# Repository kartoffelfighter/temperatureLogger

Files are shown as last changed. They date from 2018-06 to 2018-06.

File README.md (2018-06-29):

temperatureLogger Firmware alphaV2
-

**Table of contents**

 - Firmware description
 - Function description
 - New Functions
 - Comparison
 - Possibility for new milestone

**Firmware description**

temperatureLogger alphaV2 ist planned to be used for a temperature logging device based on esp8266.
The device sends its measured values using a json string to a php server api to be stored and viewed from users. temperatureLogger alphaV2 uses the new and changing pcb-layout, alphaV2 is work in progress and may be not stable to use.

alphaV2 will be recoded to a tick based firmware powered by interrupts by timer0. 
at this time alphaV2 runs millis() loop based, checking the lasted time running code, for the new sleep() function a tick based firmware is needed.

**Function description**

based on alphaV1 the firmware can already measure, sample and send values to the API (Server). 
In future, the functions should be better described here.

**New functions**
in alphaV2 especially the error handling an the improvin of new hardware-designed milestone should be implemented.

For future releases the should be a function to configure editable values from "settings.h" by API and interface.
A ping-pong communication should be implemented

**Comparison (to alphaV1)**

alphaV1 is made for the old pcb layout, some pins have changed.
alphaV2 has no more LCD support, also LCD support is not planned for the future.
alphaV2 implements new features, as a multiplexed ADC input for measuring multiple Analog Values with just one ADC.
*primary change* alphaV2 will be a tick (interrupt) based firmware for compatibility reasons to new boards in the future.

**next milestone for alphaV3**
the next milestone is planned for the first, etched pcb in january '18.

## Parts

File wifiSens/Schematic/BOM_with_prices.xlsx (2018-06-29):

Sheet: EK Übersicht
ID | Name | supplier | price per unit | link | Auf Lager | EK | Description | Datasheet
 | ESP8266 | diy_fans | 1.68 € | http://www.ebay.de/itm/ESP8266-ESP-12E-Serial-WIFI-Kabellos-Transceiver-Kabellos-Modul-LWIP-AP-STA/322715945383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 | 5 | 8.40 € | WiFi Module/µC | Link
 | MC34063 | bingogo | 0.05 € | http://www.ebay.de/itm/20Pcs-MC34063-SOP8-ON-REG-BUCK-BOOST-INV-8-DIP-NEW/232488914511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 | 20 | 1.00 € | BuckBoost stepup | Link | Projekt gesamt: | 72.22 €
 | AMS1117-3,3 | bingogo | 0.02 € | http://www.ebay.de/itm/50Stks-AMS1117-3-3-LM1117-3-3V-1A-SOT-223-Voltage-Regulator-top/232480428556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 | 50 | 1.00 € | LDO 3.3V | Link | Platine aktuell: | 6.96 €
 | DHT22 | diy_fans | 2.30 € | http://www.ebay.de/itm/DHT22-AM2302-Digital-Temperatur-Humidity-Sensor-Replace-SHT11-Arduino-Tackle/322667376882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 | 10 | 23.00 € | Temp Humid sensor | Link
 | Solar Panel | x-web-top | 1.00 € | http://www.ebay.de/itm/6V-1W-Solar-Panel-Modul-DIY-f%C3%BCr-Licht-Batterie-Handy-Ladeger%C3%A4te-Spielzeug-Nue/152683963489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 | 2 | 2.00 € |  | Link
 | 74HC132 | kessler-eletronic | 0.53 € | http://www.ebay.de/itm/5x-74HC132-SMD-NAND-Schmitt-Trigger-4-fach-SO14/111876817725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 | 5 | 2.64 € | NAND Schmit Trigger | Link
 | BSS84 | elektronik-direkt | 0.04 € | http://www.ebay.de/itm/30-x-BSS84-Kleinsignal-MOSFET-P-Channel/262316733258?ssPageName=STRK%3AMEBIDX%3AIT | 30 | 1.30 € | P-Channel Mosfet | Link
 | BC817-40 | elektronik-direkt | 0.04 € | http://www.ebay.de/itm/30-x-BC817-40-NPN-Kleinsignaltransistor-45V-500mA-SOT23/262290383155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 | 30 | 1.10 € | NPN Transistor | Link
 | LP2985 | elektronik-direkt | 0.33 € | http://www.ebay.de/itm/3x-9x-Ultra-Low-Dropout-Spannungsregler-LP2985-3-3-V-Kondensatoren-Platine/253119635496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 | 9 | 2.95 € | uLDO 3.3V | Link
 | PL2303hx | iamsn2008 | 0.36 € | http://www.ebay.de/itm/10Pcs-Pl2303hx-2303-Produktes-Ssop-28-Neues-Ic-N/232312842167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 | 10 | 3.56 € | USB UART Converter | Link
 | micro usb buchse | nn_745 | 0.12 € | http://www.ebay.de/itm/20x-Female-5Pin-SMT-Micro-USB-Socket-Adaptor-Connector-weiblich-Buchse-Anschluss/152776161688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 | 20 | 2.50 € |  | Link
 | tact switch smd | sell4joy | 0.08 € | http://www.ebay.de/itm/50pcs-4mmx4mmx1-5mm-4Pins-SMD-PCB-Momentary-Tact-Push-Button-Switch/391876007978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 | 50 | 4.01 € |  | Link
 | RB551v-30 | iamsn2008 | 0.03 € | http://www.ebay.de/itm/100Pcs-Rb551v-30-Te17-Schottky-Sod-323-Rohm-0-5A-20V-Neu-Ic-V/332195522274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 | 100 | 3.28 € | Schottky Diode | Link
 | mmbt8050 | iamsn2008 | 0.04 € | http://www.ebay.de/itm/50Pcs-Transistor-Mmbt8050-Sot-23-Npn-J3y-S8050-Smd-Neue-Ic-V/332191461244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 | 50 | 2.00 € | NPN Transistor | Link
 | µSD Socket | sellerbible | 0.09 € | https://www.ebay.de/itm/121688713134 | 50 | 4.48 € |  | Link
 | tp4056 | iamsn2008 | 0.08 € | https://www.ebay.de/itm/332214138541 | 50 | 4.00 € | LiPo Loader | Link
 | 12MhZ Oscillator |  | 0.17 € | https://www.ebay.de/itm/112688636210 | 30 | 5.00 € | Quarz Oszillator

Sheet: Exportet_BOM
Reference | Value | Footprint | Datasheet | Comment
SW1 | SW_Push | Buttons_Switches_SMD:SW_MEC_5GSH9 |  |  | Widerstände | Cap
SW2 | SW_Push | Buttons_Switches_SMD:SW_MEC_5GSH9 |  |  | 1x12 | 0,01µF
C13 | 0,01ÂµF | Capacitors_SMD:C_0603_HandSoldering |  |  | 4x470 | 0,1µF
C2 | 0,1ÂµF | Capacitors_SMD:C_0603_HandSoldering |  |  | 12x 0R0 | 100µF
C11 | 100ÂµF | Capacitors_SMD:C_0603_HandSoldering |  |  | 2x 100k | 6x 100nF
C18 | 100nF | Capacitors_SMD:C_0603_HandSoldering |  |  | 3x10k | 6x 10µF | 1x 10µ 1206 tantal
C19 | 100nF | Capacitors_SMD:C_0603_HandSoldering |  |  | 6x12k | 1x10nF
C20 | 100nF | Capacitors_SMD:C_0603_HandSoldering |  |  | 3x 1k | 2x16pF
C21 | 100nF | Capacitors_SMD:C_0603_HandSoldering |  |  | 1x1,5k | 2x 1µF
C7 | 100nF | Capacitors_SMD:C_0603_HandSoldering |  |  | 1x 220k | 1x 2,2µF
C9 | 100nF | Capacitors_SMD:C_0603_HandSoldering |  |  | 1x 330k
C14 | 10ÂµF | Capacitors_SMD:C_0603_HandSoldering | 10 | NB | 1x 3,3k
C16 | 10ÂµF | Capacitors_SMD:C_0603_HandSoldering |  | NB
C17 | 10ÂµF | Capacitors_SMD:C_0603_HandSoldering
C6 | 10ÂµF | Capacitors_SMD:C_0603_HandSoldering
C8 | 10ÂµF | Capacitors_SMD:C_0603_HandSoldering
C1 | 10nF | Capacitors_SMD:C_0603_HandSoldering
C4 | 16pF | Capacitors_SMD:C_0603_HandSoldering
C5 | 16pF | Capacitors_SMD:C_0603_HandSoldering
C12 | 1ÂµF | Capacitors_SMD:C_0603_HandSoldering
C3 | 1ÂµF | Capacitors_SMD:C_0603_HandSoldering
C15 | 2,2ÂµF | Capacitors_SMD:C_0603_HandSoldering
C10 | C | Capacitors_SMD:C_0603_HandSoldering
C22 | 10ÂµF | Capacitors_SMD:C_1206_HandSoldering
J6 | USB_OTG | Connectors:USB_Micro-B
Y1 | Crystal | Crystals:Crystal_SMD_HC49-SD_HandSoldering
RB551v-30 | D_Schottky | Diodes_SMD:D_SOD-323
D1 | RB551v-30 | Diodes_SMD:D_SOD-323
D2 | RB551v-30 | Diodes_SMD:D_SOD-323
D5 | RB551v-30 | Diodes_SMD:D_SOD-323
U2 | ESP-12E | ESP8266:ESP-12E
U1 | pl2303 | Housings_SSOP:SSOP-28_5.3x10.2mm_Pitch0.65mm
D3 | LED | LEDs:LED_0805_HandSoldering
D4 | LED | LEDs:LED_0805_HandSoldering
D6 | LED | LEDs:LED_0805_HandSoldering
TP3 | +3V3 | Pin_Headers:Pin_Header_Straight_1x01_Pitch1.00mm
TP2 | ADC | Pin_Headers:Pin_Header_Straight_1x01_Pitch1.00mm
TP4 | ADC | Pin_Headers:Pin_Header_Straight_1x01_Pitch1.00mm
TP1 | GND | Pin_Headers:Pin_Header_Straight_1x01_Pitch1.00mm
J4 | CONN_01X02 | Pin_Headers:Pin_Header_Straight_1x02_Pitch2.54mm
J5 | CONN_01X02 | Pin_Headers:Pin_Header_Straight_1x02_Pitch2.54mm
J2 | CONN_01X04 | Pin_Headers:Pin_Header_Straight_1x04_Pitch1.00mm
IC1 | DHT22 | Pin_Headers:Pin_Header_Straight_1x04_Pitch2.54mm
J3 | CONN_01X06 | Pin_Headers:Pin_Header_Straight_1x06_Pitch2.54mm
R5 | 12 | Resistors_SMD:R_0603
R24 | 470 | Resistors_SMD:R_0603
R28 | 470 | Resistors_SMD:R_0603
R30 | 470 | Resistors_SMD:R_0603
R31 | 470 | Resistors_SMD:R_0603
R11 | 0r0 | Resistors_SMD:R_0603
R12 | 0r0 | Resistors_SMD:R_0603
R13 | 0r0 | Resistors_SMD:R_0603
R14 | 0R0 | Resistors_SMD:R_0603 |  | NB
R16 | 0r0 | Resistors_SMD:R_0603
R18 | 0r0 | Resistors_SMD:R_0603
R19 | 0r0 | Resistors_SMD:R_0603
R22 | 0R0 | Resistors_SMD:R_0603
R23 | 0r0 | Resistors_SMD:R_0603
R25 | 0R0 | Resistors_SMD:R_0603
R27 | 0R0 | Resistors_SMD:R_0603
R29 | 0r0 | Resistors_SMD:R_0603
R34 | 100k | Resistors_SMD:R_0603
R35 | 100k | Resistors_SMD:R_0603
R1 | 10k | Resistors_SMD:R_0603
R2 | 10k | Resistors_SMD:R_0603
R3 | 10k | Resistors_SMD:R_0603
R10 | 12k | Resistors_SMD:R_0603
R4 | 12k | Resistors_SMD:R_0603
R6 | 12k | Resistors_SMD:R_0603
R7 | 12k | Resistors_SMD:R_0603
R8 | 12k | Resistors_SMD:R_0603
R9 | 12k | Resistors_SMD:R_0603
R20 | 1k | Resistors_SMD:R_0603
R21 | 1k | Resistors_SMD:R_0603
R26 | 1k | Resistors_SMD:R_0603
R17 | 1k5 | Resistors_SMD:R_0603
R33 | 220k | Resistors_SMD:R_0603
R32 | 330k | Resistors_SMD:R_0603
R15 | 3k3 | Resistors_SMD:R_0603
U4 | LM1117-3.3 | TO_SOT_Packages_SMD:SOT-223 |  | NB
Q1 | MMBT8050 | TO_SOT_Packages_SMD:SOT-23
Q2 | MMBT8050 | TO_SOT_Packages_SMD:SOT-23
U3 | LP2985LV | TO_SOT_Packages_SMD:SOT-23-5_HandSoldering
U5 | TP4056 | TO_SOT_Packages_SMD:SuperSOT-8
J1 | Micro_SD_Card_Det | wifiSens:Conn_uSDcard

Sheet: Signale
Name | From | connected
TXD | CON6 Serial Pins
RXD | CON6 Serial Pins
RESET | CON6 Serial Pins
+6V | Solar Panel
+3,3V |  | DHT
+Batt | Akku
DHT_DATA | DHT Sensor
USB_D+ | USB Buchse
USB_D- | USB Buchse
OTG_ID | USB Buchse
ON_OFF | LP2985LV LDO
GPIO16 |  | nRST
nRST
GPIO0 |  | Button
ADC |  | +VBATT
SD_CS | SD
SD_MOSI | SD
SD_MISO | SD
SD_CLK | SD
SD_DETECT | SD | -> +3V3 if SD plugged in
LOAD_EN | tp4056 | (needs +5V to operate)
CHRG | tp4057 | turns low while charging
STDBY | tp4058 | turns low if not charging

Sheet: Pins
GPIO0 | Button
GPIO1 | n/a
GPIO2 | STDBY
GPIO3 | na
GPIO4 | CHRG
GPIO5 | DHT_DATA
GPIO6
GPIO7 | ON_OFF
GPIO8
GPIO9
GPIO10
GPIO11 | SD_DETECT
GPIO12 | SD_MISO
GPIO13 | SD_MOSI
GPIO14 | SD_CLK
GPIO15 | LOAD_EN
GPIO16 | wakuUp

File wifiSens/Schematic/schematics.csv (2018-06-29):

Reference | Value | Footprint | Datasheet | Comment
C2 | 0,1µF | Capacitors_SMD:C_0603_HandSoldering
C1 | 10nF | Capacitors_SMD:C_0603_HandSoldering
J1 | Micro_SD_Card_Det | wifiSens:Conn_uSDcard
R1 | 10k | Resistors_SMD:R_0603
R2 | 10k | Resistors_SMD:R_0603
R3 | 10k | Resistors_SMD:R_0603
C3 | 1µF | Capacitors_SMD:C_0603_HandSoldering
U1 | pl2303 | Housings_SSOP:SSOP-28_5.3x10.2mm_Pitch0.65mm
C4 | 16pF | Capacitors_SMD:C_0603_HandSoldering
C5 | 16pF | Capacitors_SMD:C_0603_HandSoldering
Y1 | Crystal | Crystals:Crystal_SMD_HC49-SD_HandSoldering
C6 | 10µF | Capacitors_SMD:C_0603_HandSoldering
C7 | 100nF | Capacitors_SMD:C_0603_HandSoldering
C8 | 10µF | Capacitors_SMD:C_0603_HandSoldering
C9 | 100nF | Capacitors_SMD:C_0603_HandSoldering
Q1 | MMBT8050 | TO_SOT_Packages_SMD:SOT-23
Q2 | MMBT8050 | TO_SOT_Packages_SMD:SOT-23
R5 | 12 | Resistors_SMD:R_0603
R4 | 12k | Resistors_SMD:R_0603
U2 | ESP-12E | ESP8266:ESP-12E
J2 | CONN_01X04 | Pin_Headers:Pin_Header_Straight_1x04_Pitch1.00mm
TP3 | +3V3 | Pin_Headers:Pin_Header_Straight_1x01_Pitch1.00mm
TP1 | GND | Pin_Headers:Pin_Header_Straight_1x01_Pitch1.00mm
TP2 | ADC | Pin_Headers:Pin_Header_Straight_1x01_Pitch1.00mm
C11 | 100µF | Capacitors_SMD:C_0603_HandSoldering
R7 | 12k | Resistors_SMD:R_0603
R8 | 12k | Resistors_SMD:R_0603
R9 | 12k | Resistors_SMD:R_0603
R10 | 12k | Resistors_SMD:R_0603
R6 | 12k | Resistors_SMD:R_0603
C10 | C | Capacitors_SMD:C_0603_HandSoldering
U4 | LM1117-3.3 | TO_SOT_Packages_SMD:SOT-223 |  | NB
U3 | LP2985LV | TO_SOT_Packages_SMD:SOT-23-5_HandSoldering
U5 | TP4056 | TO_SOT_Packages_SMD:SuperSOT-8
C14 | 10µF | Capacitors_SMD:C_0603_HandSoldering | 10 | NB
C16 | 10µF | Capacitors_SMD:C_0603_HandSoldering |  | NB
R14 | 0R0 | Resistors_SMD:R_0603 |  | NB
R11 | 0r0 | Resistors_SMD:R_0603
C12 | 1µF | Capacitors_SMD:C_0603_HandSoldering
C13 | 0,01µF | Capacitors_SMD:C_0603_HandSoldering
C15 | 2,2µF | Capacitors_SMD:C_0603_HandSoldering
R15 | 3k3 | Resistors_SMD:R_0603
D2 | RB551v-30 | Diodes_SMD:D_SOD-323
R13 | 0r0 | Resistors_SMD:R_0603
R16 | 0r0 | Resistors_SMD:R_0603
R17 | 1k5 | Resistors_SMD:R_0603
R20 | 1k | Resistors_SMD:R_0603
R21 | 1k | Resistors_SMD:R_0603
C17 | 10µF | Capacitors_SMD:C_0603_HandSoldering
R18 | 0r0 | Resistors_SMD:R_0603
R19 | 0r0 | Resistors_SMD:R_0603
D3 | LED | LEDs:LED_0805_HandSoldering
D4 | LED | LEDs:LED_0805_HandSoldering
D1 | RB551v-30 | Diodes_SMD:D_SOD-323
RB551v-30 | D_Schottky | Diodes_SMD:D_SOD-323
R12 | 0r0 | Resistors_SMD:R_0603
J6 | USB_OTG | Connectors:USB_Micro-B
J3 | CONN_01X06 | Pin_Headers:Pin_Header_Straight_1x06_Pitch2.54mm
J4 | CONN_01X02 | Pin_Headers:Pin_Header_Straight_1x02_Pitch2.54mm
J5 | CONN_01X02 | Pin_Headers:Pin_Header_Straight_1x02_Pitch2.54mm
R27 | 0R0 | Resistors_SMD:R_0603
R22 | 0R0 | Resistors_SMD:R_0603
R25 | 0R0 | Resistors_SMD:R_0603
IC1 | DHT22 | Pin_Headers:Pin_Header_Straight_1x04_Pitch2.54mm
C20 | 100nF | Capacitors_SMD:C_0603_HandSoldering
C18 | 100nF | Capacitors_SMD:C_0603_HandSoldering
C19 | 100nF | Capacitors_SMD:C_0603_HandSoldering
R24 | 470 | Resistors_SMD:R_0603
R23 | 0r0 | Resistors_SMD:R_0603
C21 | 100nF | Capacitors_SMD:C_0603_HandSoldering
C22 | 10µF | Capacitors_SMD:C_1206_HandSoldering
R26 | 1k | Resistors_SMD:R_0603
D5 | RB551v-30 | Diodes_SMD:D_SOD-323
SW1 | SW_Push | Buttons_Switches_SMD:SW_MEC_5GSH9
R28 | 470 | Resistors_SMD:R_0603
R29 | 0r0 | Resistors_SMD:R_0603
R30 | 470 | Resistors_SMD:R_0603
R31 | 470 | Resistors_SMD:R_0603
SW2 | SW_Push | Buttons_Switches_SMD:SW_MEC_5GSH9
D6 | LED | LEDs:LED_0805_HandSoldering
R33 | 220k | Resistors_SMD:R_0603
R34 | 100k | Resistors_SMD:R_0603
R32 | 330k | Resistors_SMD:R_0603
R35 | 100k | Resistors_SMD:R_0603
TP4 | ADC | Pin_Headers:Pin_Header_Straight_1x01_Pitch1.00mm

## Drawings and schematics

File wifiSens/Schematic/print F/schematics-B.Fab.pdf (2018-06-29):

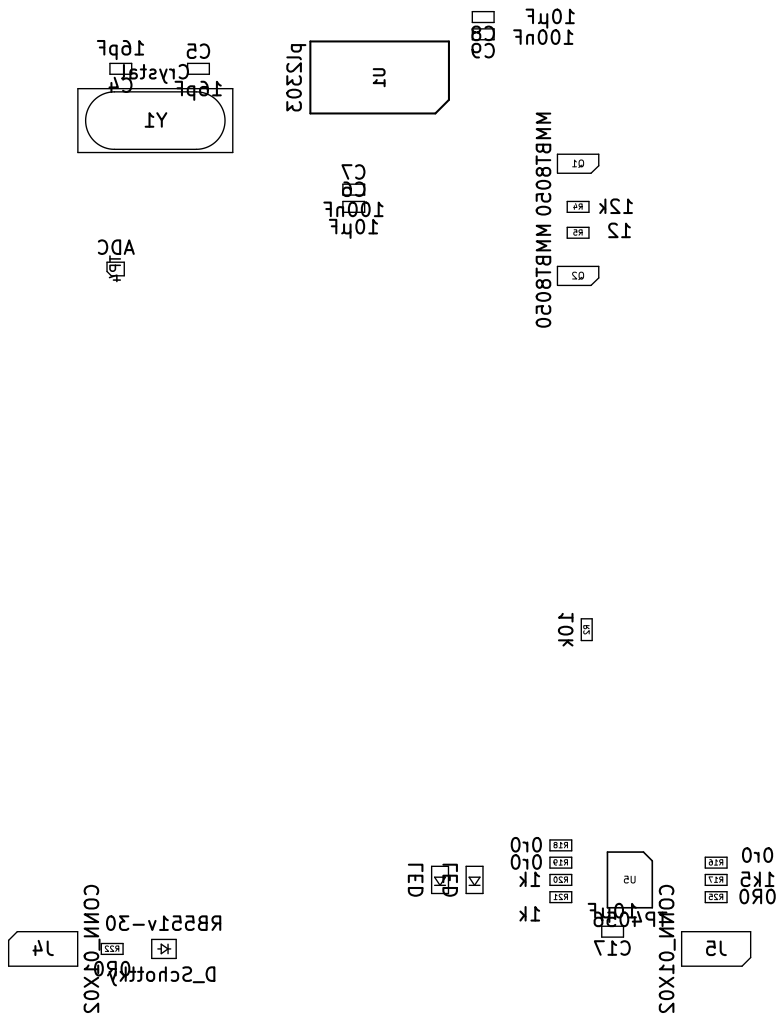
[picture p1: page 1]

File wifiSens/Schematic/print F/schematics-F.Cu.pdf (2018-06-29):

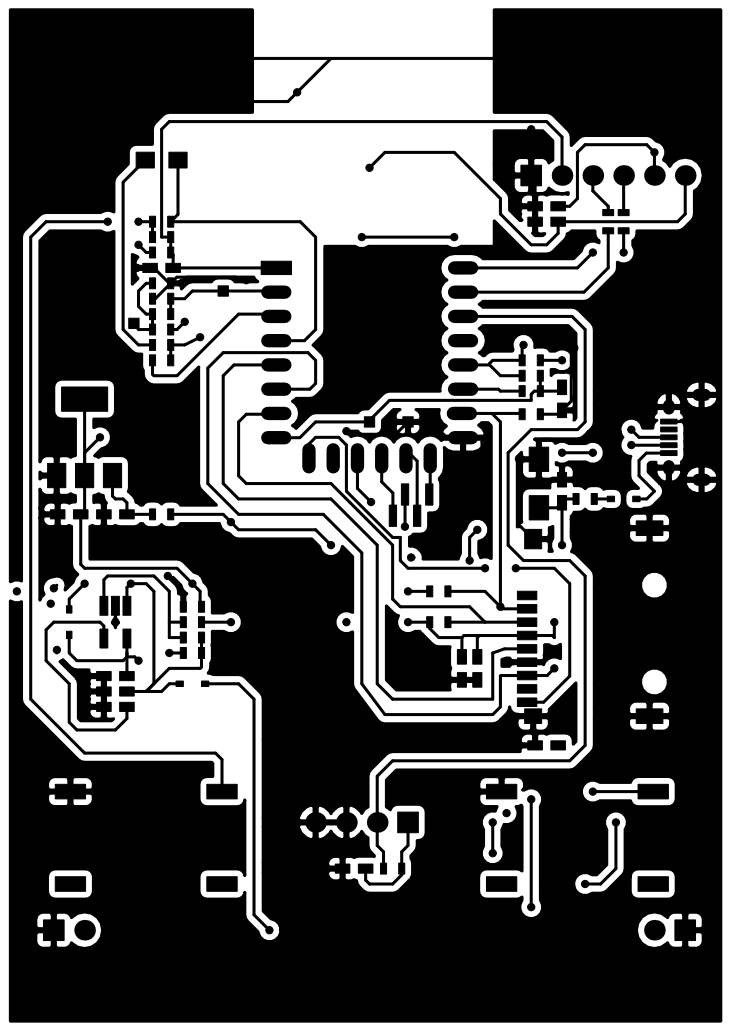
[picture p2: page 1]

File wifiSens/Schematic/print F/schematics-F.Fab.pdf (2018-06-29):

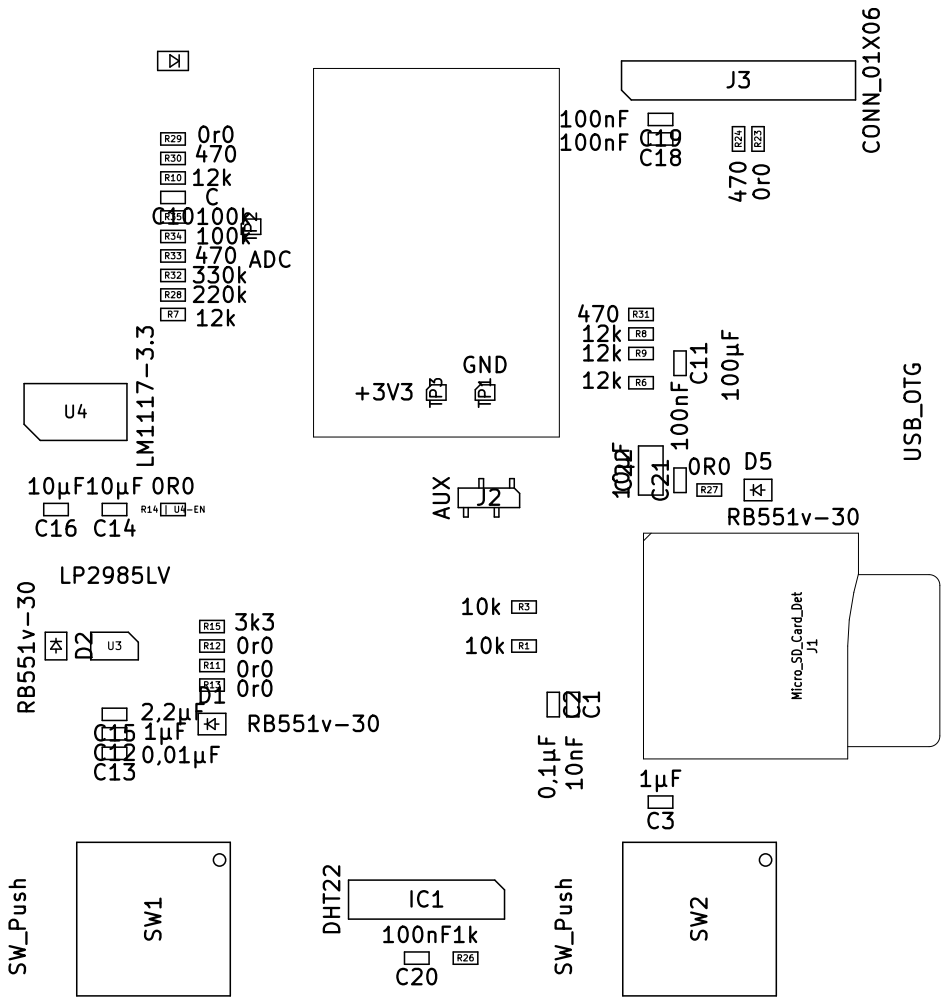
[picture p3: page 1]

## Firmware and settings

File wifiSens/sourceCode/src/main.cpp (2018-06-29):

#include <Arduino.h>
#include <ESP8266WiFi.h>
#include <ESP8266HTTPClient.h> // http client
#include <ESP8266mDNS.h>       // mDNS package resolver for wifi_Server
#include <ESP8266WebServer.h>  // Webserver for wifi_Server
#include <SPI.h>               // SPI for SD-Card
#include <SdFat.h>                // SD-Card
#include <ArduinoJson.h>       // JSON Library
#include <TimeLib.h>           // Time library
#include <DHT.h>               // DHT Sensor Library
#include <ArduinoOTA.h>        // OTA Update library

#include "settings.h"  //settings file
#include "lang.h"      // language File
#include "pins.h"      // pin config
#include "functions.h" // functions file
#include "boot.h" // startup relevant code
#include "loop.h"      // the loop (cycle())
#include "OTA.h"  // OTA Updates relevant Code

void setup()
{
    Serial.begin(115200);
    pinMode(ADC, INPUT);
    pinMode(accuLoading, INPUT);
    pinMode(accuFull, INPUT);
    dht.setup(DHT_DATA_PIN);
    // ignore setup, booting script running at loop
    enableOTA();
}

void loop()
{
    boot();              // call boot script to test system and establish wifi connection etc. can be recalled, if bool booted is set to false
    cycle();             // the "loop"
    ArduinoOTA.handle(); // OTA Update Handler
}
=======
#include <Arduino.h>
#include <ESP8266WiFi.h>
#include <ESP8266HTTPClient.h>    // http client
#include <ArduinoJson.h>      // JSON Library
#include <TimeLib.h>      // Time library
#include <dht.h>  // DHT Sensor Library


#include "settings.h"  //settings file
#include "lang.h"   // language File
#include "pins.h" // pin config
#include "functions.h"  // functions file

#include "boot.h"     // startup relevant code

int lastMinute = 0;   // counter for status information
int lastUpdateDay = 0;  // counter for updating time
int lastMeasure = 0;  // counter for last measure



void setup() {
    Serial.begin(115200);
    pinMode(ADC, INPUT);
    dht.setup(DHT_DATA_PIN);
    // ignore setup, booting script running at loop
}

void loop() {
boot();   // call boot script to test system and establish wifi connection etc. can be recalled, if bool booted is set to false
sample();
if((millis() - lastMeasure)/60000 >= INTERVALL){     // replaced minute() with millis(), minute will overurun after one hour and the sensor wont work anymore.
  if(!sendValue(0x00, tempSample, humidSample, 0x01, accuSample)){
    Serial.println("query failed");
      return;
  }
  lastMeasure = millis();
}

if((millis() - lastMinute)/60000 >= 5){
  alive();
  lastMinute = millis();
}
if(millis() - 24*60*60*1000 >= lastUpdateDay) {   // reinitialize after 1 Day
  //booted = false;
  lastUpdateDay = millis();
}
}

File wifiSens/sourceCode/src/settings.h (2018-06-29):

// ===== superglobal settings ===== //
#define STORE_ON_FLASH false        // enable settings to be stored in eeprom
#define SETUP false         // enable setup at first boot

// ===== DEBUG ===== (not possible in eeprom_settings mode)
#define WAITFORSERIAL false // debug information, waites to boot until serial monitor is connected
#define USE_SD_CRC 0  // debug information for CRC Check

// ===== WIFI ======
#define SSID "Volks.Funk"
#define WiFiPass "ungueltigeeingabe"

// ===== Server Connection in push mode =====
#define SENSID "0x002"      // Note: The SENSID is also the HOST-Name! (Host-Name: SENS[SENSID].local)
#define GMTplus 1 // time adjust plus the GMT in h
#define API_KEY "FucK4sch001"
#define SERVER_ADDR "http://kruemel:1337/temperatureLogger/html/api.php"
#define SERVER_HOST "kruemel"
#define SERVER_PORT 1337
#define SERVER_BASE_URL "/temperatureLogger/html/api.php"

// ===== Measurement related
#define INTERVALL 1   // time in minuts between two measures
#define SAMPLE_RATE  5  // how often should measure be called while sampling
#define SAMPLES 25 // Sampletime in Seconds before a value is valid
#define DHT_TYPE "DHT22"  // define the DHT Sensor Type (Lib supports DHT11 / DHT22 / DHT21)
#define OFFSET 273.15   // Offset for negative Temperatures (0K)

// ===== SD related

#define error(msg) sd.errorHalt(F(msg)) // Error messages stored in flash.
#define FILE_EXTENSION ".csv"   // file extension on logged data on sd card
#define MEASUREMENT_DIR "values"    // directory where files will be placed

// initialisation of globals 
// measured vallue store
long lastRenew = 0; // unix time for last renewed time
long loadingSince = 0;  // millis since accu is loading
float humidity, temperature, accu;
float humidSample, tempSample, accuSample;

// determination of accu is loading
bool AccuLoading, AccuFull; // booleans for loading accu or accu full

// counters
int lastMinute = 0;   // counter for status information
int lastUpdateDay = 0;  // counter for updating time
int lastMeasure = 0;  // counter for last measure
int millisBeginnSampling = 0;


// sd related
//int fileNameSize = sizeof(MEASUREMENT_DIR) + sizeof(FILE_EXTENSION) + 8;
char fileName[25];


// ====== Config dht Sensor for Temperature and humidity measurement
DHT dht; // init dht sensor

// ====== Config sd card and fatLib
SdFat sd;   // SD config
SdFile file; // File config



///////////////////////////////////////////////////////////////////////////////////////////////////////////
// Settings file on SD Card
//
/*  settings.conf layout:
// add credentials after = in brackets

// wifi related
[SSID=SSID]         // wifi SSID
[WiFiPass=PASS]     // the wifi password
[SENSID=0x001]      // has to be HEX value with starting 0x followed by 3 characters (000 - FFF is possible)
// client/server/sdlogmode
[mode=4]            // modes table: 0 = do not operate anything; 1 = client only; 2 = server only; 3 = sd card only; 4 = client + sd; 5 = server + sd; 6 = client + server + sd     (in all modes you need this sd card...)

// client config (ignore if client mode is not used)
[GMTplus=1]         // set time offset in hours (only positive values supported)
[API_KEY=KEY]       // API Key to connect do database server api
[SERVER_ADDR=http://server:port/path/to/api.php]    // full path to api file on webserver
[SERVER_HOST=server]   // hostname of webserver
[SERVER_PORT=1337]     // port of webserver
[SERVER_BASE_URL=/path/to/api.php]  // blank path to api

// measurement related settings
[INTERVAL=1]        // time in minutes between two measures
[SAMPLE_RATE=5]     // while sampling, sample rate defines how often a pure measure of values is called
[SAMPLES=25]        // time in seconds how long a samples duration is, until a value is valid
[DHT_TYPE=DHT22]    // Type of sensor, possible: DHT11, DHT21, DHT22 ; default: DHT22
[OFFSET=273.15]     // OFFSET, added to temperature to provide negative values (needs to be identical to API)


// SD card related settings
[MEASUREMENT_DIR=values]    // directory on SD-card, where measurefiles should be stored
[FILE_EXTENSION=.csv]       // file extension of stored values


// END OF FILE

*/
// EEPROM SETTINGS
/*
#define SSID "Volks.Funk"
#define WiFiPass "ungueltigeeingabe"

// ===== Server Connection in push mode =====
#define SENSID "0x005"      // Note: The SENSID is also the HOST-Name! (Host-Name: SENS[SENSID].local)
#define GMTplus 1 // time adjust plus the GMT in h
#define API_KEY "FucK4sch001"
#define SERVER_ADDR "http://kruemel:1337/temperatureLogger/html/api.php"
#define SERVER_HOST "kruemel"
#define SERVER_PORT 1337
#define SERVER_BASE_URL "/temperatureLogger/html/api.php"
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

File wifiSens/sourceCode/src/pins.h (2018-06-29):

// define default pin config

// NodeMCU 1.0


#define ADC A0
#define DHT_DATA_PIN 5 //NodeMCU: D1

#define WakeUp 16 // NodeMCU: D0
#define BUTTON 0 // NodeMCU: D3

#define accuLoading CHRG 
#define accuFull STDBY 

#define POWER_SOURCE 14 // NodeMCU: D5
#define SD_CS 15    // NodeMCU D2

#define SD_DETECT 11      // pin on SD Card, gets HIGH if SD Card is inserted

#define LOAD_EN 15        // pin on BatteryLoader, set to high to start loading
#define CHRG 4           // pin on BetteryLoader, becomes low while loading
#define STDBY 2          // pin on BatteryLoader, becomes low if battery full

#define ONOFF 7          // signal to turn on LDO chip

/*
 Different pin configs:                                      _________________
 || used as | Arduino IDE (identical to esp8266)|| NodeMCU ||O--------------O|| NodeMCU | Arduino IDE (identical to esp8266)|| used as ||
 || ADC     | A0                                || A0      ||||+          +|||| D0      | 16                                || WakueUp ||
 ||         | GND                               || GND     ||||+          +|||| D1      | 5                                 || DHT     ||
 ||         | Reserved                          || VU      ||||+          +|||| D2      | 4                                 || Loading ||
 ||         | 10                                || SD3     ||||+     N    +|||| D3      | 0                                 || Button  ||
 ||         | 9                                 || SD2     ||||+     o    +|||| D4      | 2                                 || Full    ||
 ||         | MOSI                              || SD1     ||||+     d    +|||| 3V3     | 3V3                               || DHT     ||
 ||         | CS                                || CMD     ||||+     e    +|||| GND     | GND                               || DHT     ||
 ||         | MISO                              || SDO     ||||+     M    +|||| D5      | 14                                ||         ||
 ||         | SCLK                              || CLK     ||||+     C    +|||| D6      | 12                                ||         ||
 ||         | GND                               || GND     ||||+     U    +|||| D7      | 13                                ||         ||
 ||         | 3V3                               || 3V3     ||||+          +|||| D8      | 15                                ||         ||
 ||         | EN                                || EN      ||||+          +|||| RX      | 3                                 ||         ||
 ||         | RESET                             || RST     ||||+          +|||| TX      | 1                                 ||         ||
 ||         | GND                               || GND     ||||+          +|||| GND     | GND                               ||         ||
 ||         | Vin                               || Vin     ||||+          +|||| 3V3     | 3V3                               ||         ||
 || used as | Arduino IDE (identical to esp8266)|| NodeMCU ||O--------------O|| NodeMCU | Arduino IDE (identical to esp8266)|| used as ||
*/
=======
// define default pin config

// NodeMCU 1.0


#define ADC A0
#define DHT_DATA_PIN 5 //NodeMCU: D1

#define WakeUp 16 // NodeMCU: D0
#define BUTTON 0 // NodeMCU: D3
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

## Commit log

2017-12-09 fixed table head (wrong name, Sensor instead of Meause ID)
2017-12-09 added alive() serial function, added sample() and measure() funktion
2017-12-09 minor changes + bugfixes
    [main.cpp, pins.h, settings.h]
2017-12-20 removed some old values, added OFFSET for Temperature
2017-12-20 added Accuspannung, added Offset to temperature calculation
2017-12-20 test file for styled temperature graphs
2017-12-20 added schematic and kicad libraries
    [schematics.kicad_pcb, schematics.sch]
2017-12-20 analogMeasure() function to read analog pin (reads accu atm)
2017-12-20 removed lcd, added pin description ascii-image
2018-01-28 testing porpuse
    [31122017.csv, default.csv]
2018-01-28 added debounce() routine for exact button termination
2018-01-28 moved arduino loop() to loop file to trim main.cpp
2018-01-28 changed pin config
2018-01-28 example sensor.conf file for sd card configuration
2018-01-28 fixed delays and lastRenew bug (lastRenew was GMT time, not sensorTime)
2018-01-28 edited pin config for pcb v1.1
2018-01-28 gerber files for pcb with aux 4x1mm pin header
    [schematics-B.Cu.gbr, schematics-B.Mask.gbr, schematics-B.SilkS.gbr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]
2018-01-28 gerber files for pcb with smd aux
    [schematics-B.Cu.gbl, schematics-B.Mask.gbs, schematics-B.SilkS.gbo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]
2018-01-28 gerber files with 4x1mm aux PROTEL (pcb v1.0)
    [schematics-B.Cu.gbl, schematics-B.Mask.gbs, schematics-B.SilkS.gbo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]
2018-01-28 used libs for kicad, diy components
2018-01-28 added sd slot
2018-01-28 pcb v1.1 (smd aux) zip
2018-01-28 pcb v1.0 (header aux) zip
2018-01-28 netlist for pcb v1.0
2018-01-28 schematic v1.0
    [file5A51535C.sch, file5A51537C.sch, file5A51538F.sch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]
2018-01-28 2: Auto stash before rebase of "sola-git/master"
    [schematics.kicad_pcb]
2018-03-11 moved to ubuntu
    [31122017.csv, BOM_with_prices.xlsx, default.csv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]
